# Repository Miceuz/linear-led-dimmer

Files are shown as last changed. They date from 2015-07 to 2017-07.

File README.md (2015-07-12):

# linear-led-dimmer
A linear dimmer for 6W - 12W LED pannels.

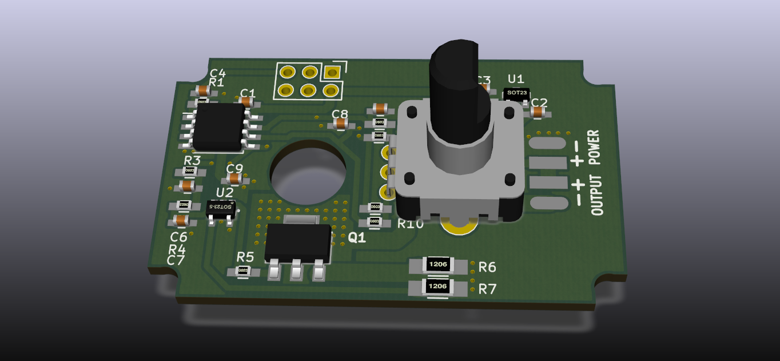
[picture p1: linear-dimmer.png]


This dimmer has to burn some power in order to dimm leds for custom made LED pannel used in cinema settings. We need to resort to crude linear dimming in order to avoid any kind of flicker on camera.



More info and eye candy here:

* Led dimmer on set
* Leds for the light panel
* A cnc cut aluminium case
* 3d printing a grid for led panels
* Led panel for cinema lighting

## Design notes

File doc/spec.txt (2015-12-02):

* Sukurta kino operatoriaus
* Labai aukšta spalvinė kokybė
* Funkcionalus dizainas, 10mm storio, pragalvotas tvirtinimas.
* Su gridu.

 * kur pozicionuoti kitų šviestuvų atžvilgiu?
 * pro pro yra sunkiau nei kitur
 * gasdina LiIon baterija, pirščiukai paprasčiau
 * Kiek laiko
 * Dydis
 * Svoris

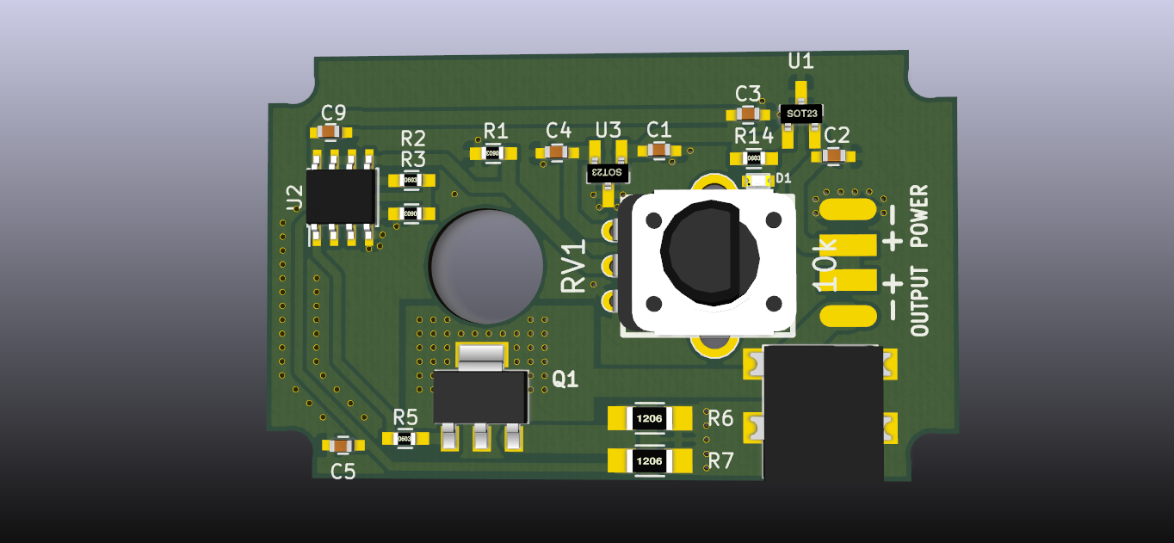
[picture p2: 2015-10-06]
linear-dimmer-v2.0-top.png

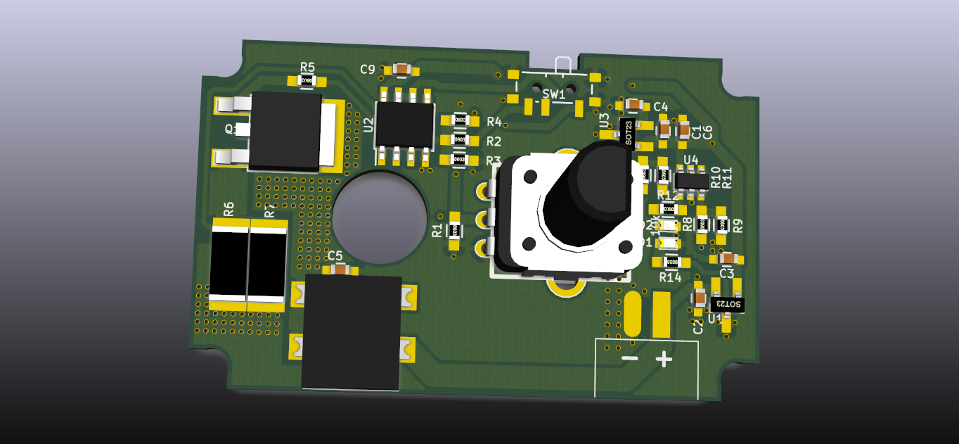
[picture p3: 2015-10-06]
linear-dimmer-v2.0-long-edge-conn.png

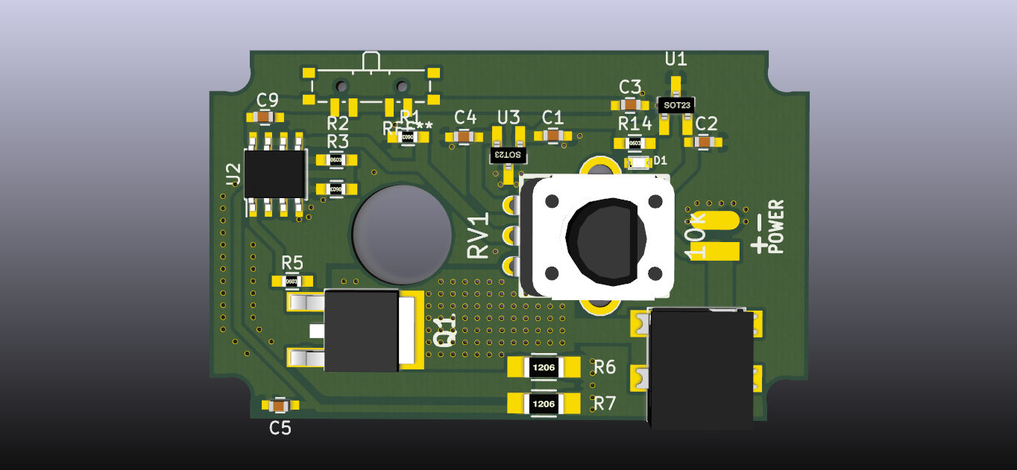
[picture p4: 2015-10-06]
linear-dimmer-v2.0-switch.png

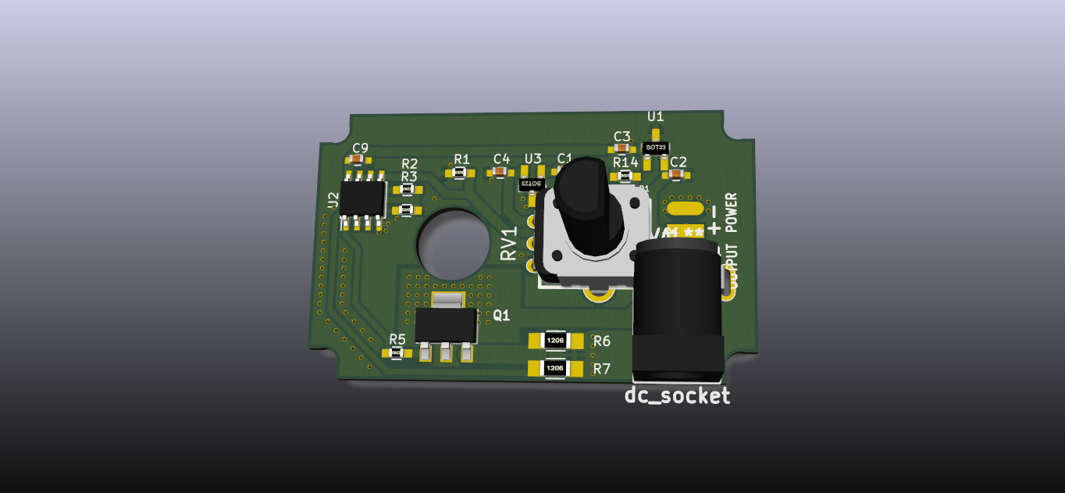
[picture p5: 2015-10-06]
linear-dimmer-v2.0-netelpa.png

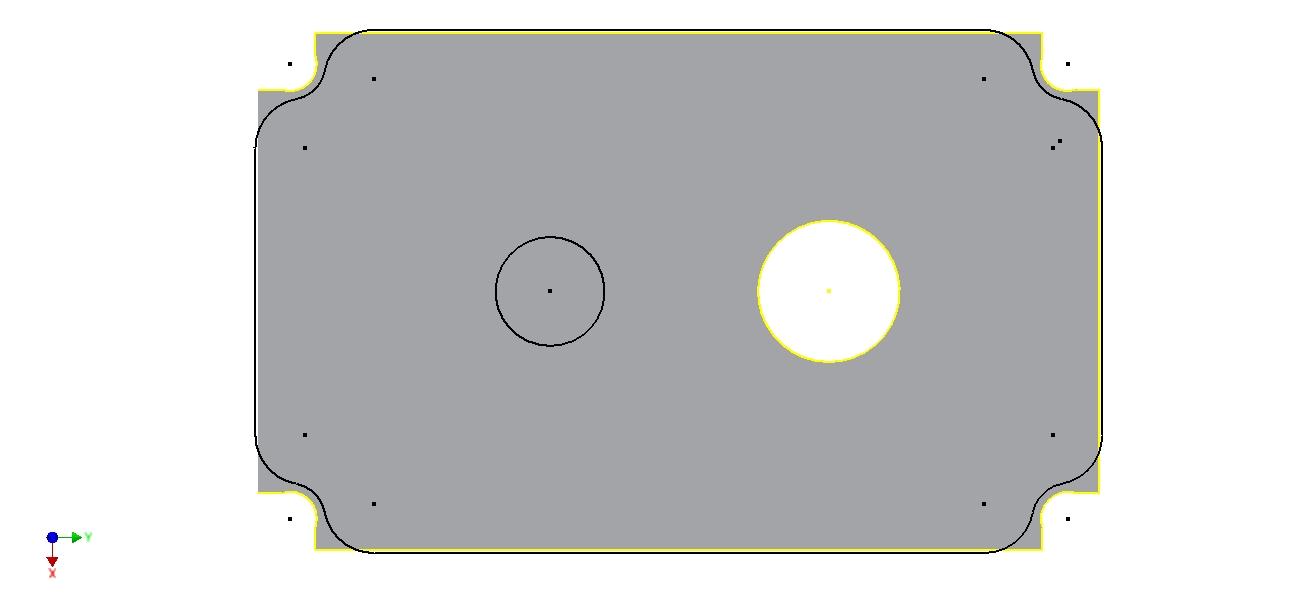
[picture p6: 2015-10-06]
doc/safeline.jpg

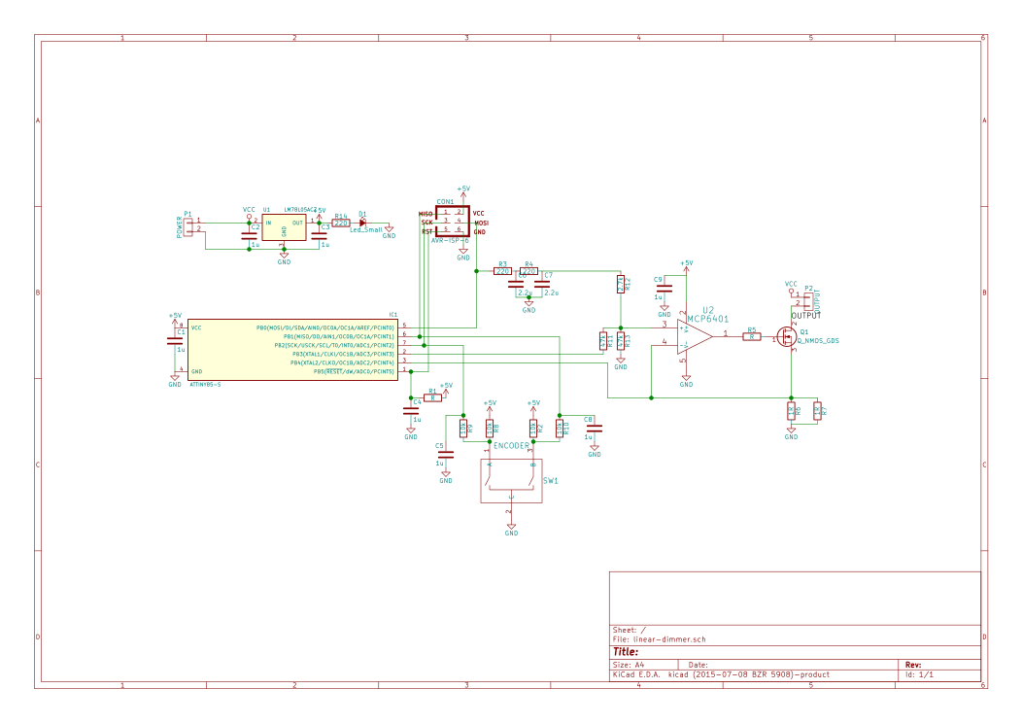
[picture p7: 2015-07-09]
linear-dimmer.sch.png

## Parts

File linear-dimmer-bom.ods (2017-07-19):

Id | Designator | Package | Quantity | Designation | Supplier and ref | Mfg ref | Price @ 10 | # on board
1 | D2 | Led_0603 | 1 | RED |  |  |  | 1 | 0
2 | P1 | pin_socket_2 | 1 | POWER | DNP |  |  | 1 | 0
3 | RV1 | trimmer_alps-rk09k1130ah1 | 1 | 10k | 1191725 (http://lt.farnell.com/alps/rk09k11310kb/pot-rotary-10k-17mm-20/dp/1191725) | RK09K11310KB | 1.35 | 1 | 1.35
4 | C4,C1,C3,C2,C9,C5,C6 | C_0603_HandSoldering | 7 | 1u |  |  | 0.02 | 7 | 0.14
5 | U3 | SOT-23_Handsoldering | 1 | REF3012 | 1470321 (http://lt.farnell.com/texas-instruments/ref3012aidbzt/voltage-ref-series-1-25v-sot-23/dp/1470321) | REF3012AIDBZT | 1.58 | 1 | 1.58
6 | U1 | SOT-23_Handsoldering | 1 | LM78L05ACZ | 1476698 (http://lt.farnell.com/taiwan-semiconductor/ts78l05cx-rf/reg-3-terminal-100ma-smd-sot-23/dp/1476698) | TS78L05CX RF | 0.43 | 1 | 0.43
7 | Q1 | d-pak | 1 | BUK6207-55C | 1863263 (http://lt.farnell.com/nxp/buk6207-55c/mosfet-n-ch-55v-90a-sot428/dp/1863263) | BUK6207-55C | 1.09 | 1 | 1.09
8 | CON1 | WURTH694102107102 | 1 | BARREL_JACK | 2472140 | 694102107102 | 0.78 | 1 | 1.64
9 | D1 | Led_0603 | 1 | BLUE |  |  |  | 1 | 0
10 | R3,R9,R10 | R_0603_HandSoldering | 3 | 10k | 2379939 (http://lt.farnell.com/panasonic-electronic-components/erj3rbd1002v/res-thick-film-10k-0-5-50v-0603/dp/2379939) | ERJ3RBD1002V | 0.044 | 3 | 0.132
11 | R1 | R_0603_HandSoldering | 1 | 2k | 1527506 (http://lt.farnell.com/te-connectivity-neohm/cpf0603f2k0c1/resistor-0603-2k0-1-50ppm/dp/1527506) | CPF0603F2K0C1 | 0.076 | 1 | 0.076
12 | R2 | R_0603_HandSoldering | 1 | 17.4k | 2138436 (http://lt.farnell.com/vishay-draloric/crcw060317k4fkea/resistor-0603-17k4-1/dp/2138436) | CRCW060317K4FKEA | 0.016 | 1 | 0.016
13 | R5,R14,R12 | R_0603_HandSoldering | 3 | 220 |  |  | 0.01 | 3 | 0.03
14 | U2 | SOIC-8_3.9x4.9mm_Pitch1.27mm | 1 | MCP6072 | 1715857 (http://lt.farnell.com/microchip/mcp6072-e-sn/op-amp-dual-1-8v-1-2mhz-8soic/dp/1715857) | MCP6072-E/SN | 0.65 | 1 | 0.65
15 | R7,R6 | r_2512 | 2 | 1R | 1100070 (http://lt.farnell.com/welwyn/lr2512-r50fw/resistor-0-5ohm-2w-2512/dp/1100070) | LR2512-R50FW | 0.86 | 2 | 1.72
16 | R4 | R_0603_HandSoldering | 1 | 3.74k | 1527534 (http://lt.farnell.com/te-connectivity-neohm/cpf0603f3k74c1/resistor-0603-3k74-1-50ppm/dp/1527534) | CPF0603F3K74C1 | 0.0317 | 1 | 0.0317
17 | R8 | R_0603_HandSoldering | 1 | 78.7k | 1527679 (http://lt.farnell.com/te-connectivity-neohm/cpf0603f78k7c1/resistor-0603-78k7-1-50ppm/dp/1527679) | CPF0603F78K7C1 | 0.077 | 1 | 0.077
18 | R11 | R_0603_HandSoldering | 1 | 1M |  |  | 0.01 | 1 | 0.01
19 | SW1 | SW_SPDT_PCM12 | 1 | Switch_SPDT_x2 | 9575146 (http://lt.farnell.com/c-k-components/pcm12smtr/switch-spdt-0-3a-6vdc-smd/dp/9575146) | PCM12SMTR | 0.79 | 1 | 0.79
20 | U4 | sot23-6 | 1 | MCP65R41T | 1863965 (http://lt.farnell.com/microchip/mcp65r41t-2402e-chy/ic-comp-lp-single-6sot23/dp/1863965) | MCP65R41T-2402E/CHY | 0.31 | 1 | 0.31
21 | Output plug |  | 1 |  | 490-PP3-002C | PP3-002C | 0.96 | 1 | 0.96
22 | Lightpipe |  | 1 |  | 2293483 |  | 0.429 | 1 | 0.429
23 | PCB |  | 1 |  |  |  | 1 | 1 | 1
 |  |  |  |  |  |  |  |  | 12.4617

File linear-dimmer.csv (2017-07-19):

Id | Designator | Package | Quantity | Designation | Supplier and ref
1 | D2 | Led_0603 | 1 | RED
2 | P1 | pin_socket_2 | 1 | POWER
3 | RV1 | trimmer_alps-rk09k1130ah1 | 1 | 10k
4 | C4,C1,C3,C2,C9,C5,C6 | C_0603_HandSoldering | 7 | 1u
5 | U3 | SOT-23_Handsoldering | 1 | REF3012
6 | U1 | SOT-23_Handsoldering | 1 | LM78L05ACZ
7 | Q1 | d-pak | 1 | BUK6207-55C
8 | CON1 | WURTH694102107102 | 1 | BARREL_JACK
9 | D1 | Led_0603 | 1 | BLUE
10 | R3,R9,R10 | R_0603_HandSoldering | 3 | 10k
11 | R1 | R_0603_HandSoldering | 1 | 2k
12 | R2 | R_0603_HandSoldering | 1 | 17.4k
13 | R5,R14,R12 | R_0603_HandSoldering | 3 | 220
14 | U2 | SOIC-8_3.9x4.9mm_Pitch1.27mm | 1 | MCP6072
15 | R7,R6 | r_2512 | 2 | 1R
16 | R4 | R_0603_HandSoldering | 1 | 3.74k
17 | R8 | R_0603_HandSoldering | 1 | 78.7k
18 | R11 | R_0603_HandSoldering | 1 | 1M
19 | SW1 | SW_SPDT_PCM12 | 1 | Switch_SPDT_x2
20 | U4 | sot23-6 | 1 | MCP65R41T

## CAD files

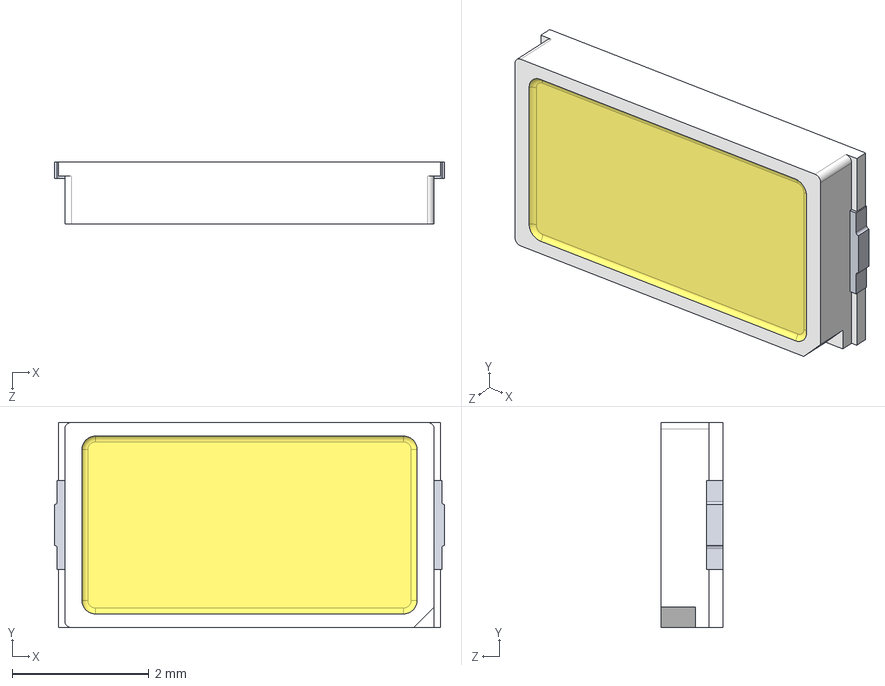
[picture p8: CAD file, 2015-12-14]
3d/User Library-PLCC-2white.step
5.70 x 3.00 x 0.9 mm

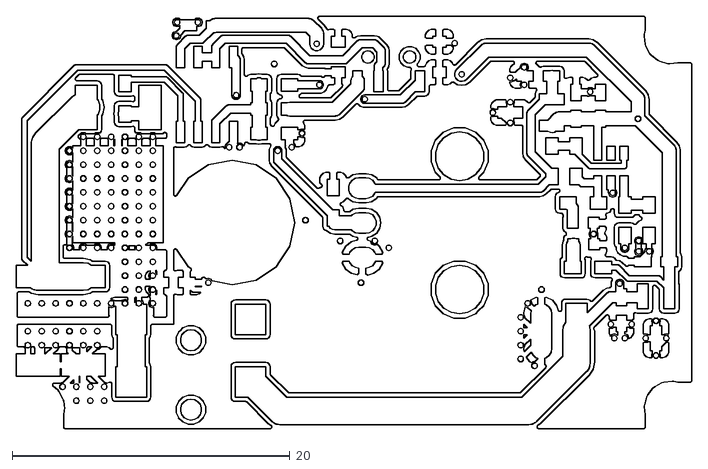
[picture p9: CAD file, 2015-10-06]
dxf/linear-dimmer-F_Cu.dxf
48.7 x 29.7

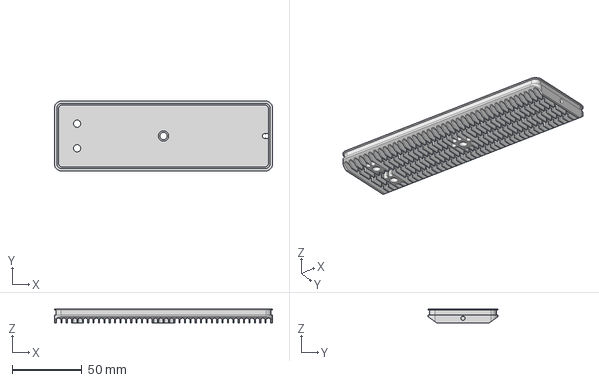
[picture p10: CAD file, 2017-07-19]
pannel/doc/156x50x10 V7 alu pcb V1.stp
156.0 x 50.0 x 10.0 mm

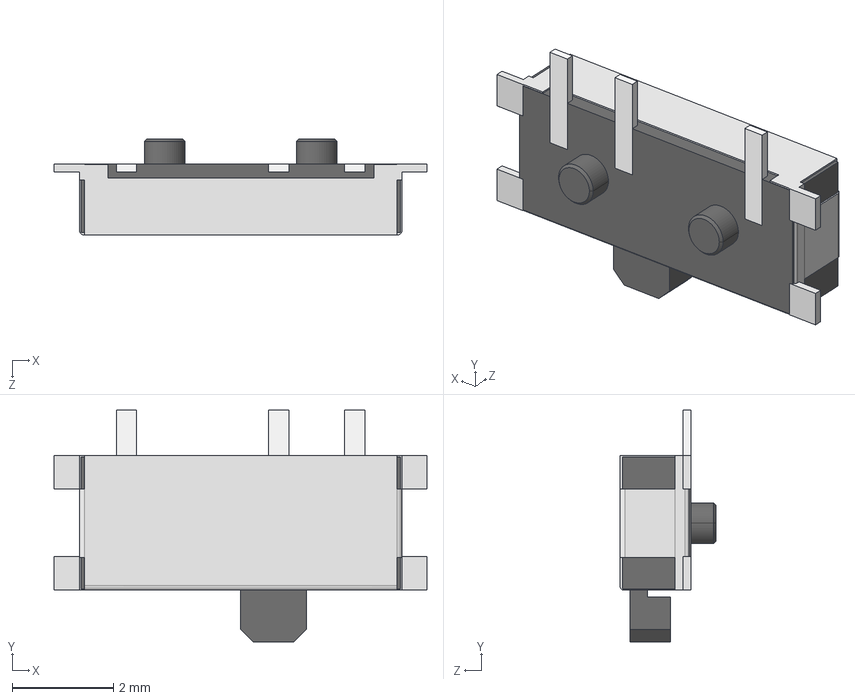
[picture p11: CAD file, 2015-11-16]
3d/User Library-pcm12smtr.STEP
7.35 x 4.57 x 1.90 mm
User Library-pcm12smtr_pcm12smtr_body
User Library-pcm12smtr_pcm12smtr_shield
User Library-pcm12smtr_pcm12smtr_pins
User Library-pcm12smtr_pcm12smtr_slider

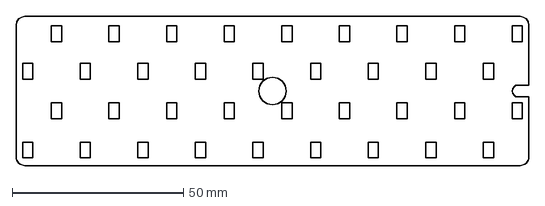
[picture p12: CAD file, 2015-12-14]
doc/Alu-PCB V3.dxf
149.5 x 43.5 mm

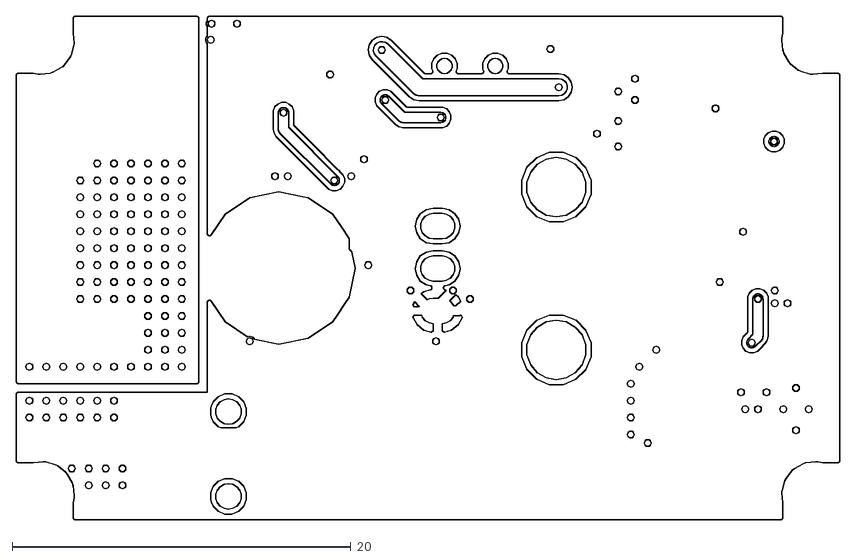
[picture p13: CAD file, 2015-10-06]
dxf/linear-dimmer-B_Cu.dxf
48.6 x 29.7

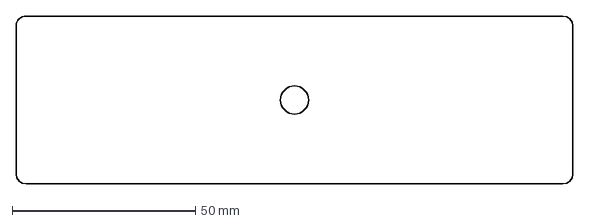
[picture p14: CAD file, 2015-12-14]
doc/Alu-PCB.dxf
151.8 x 45.8 mm

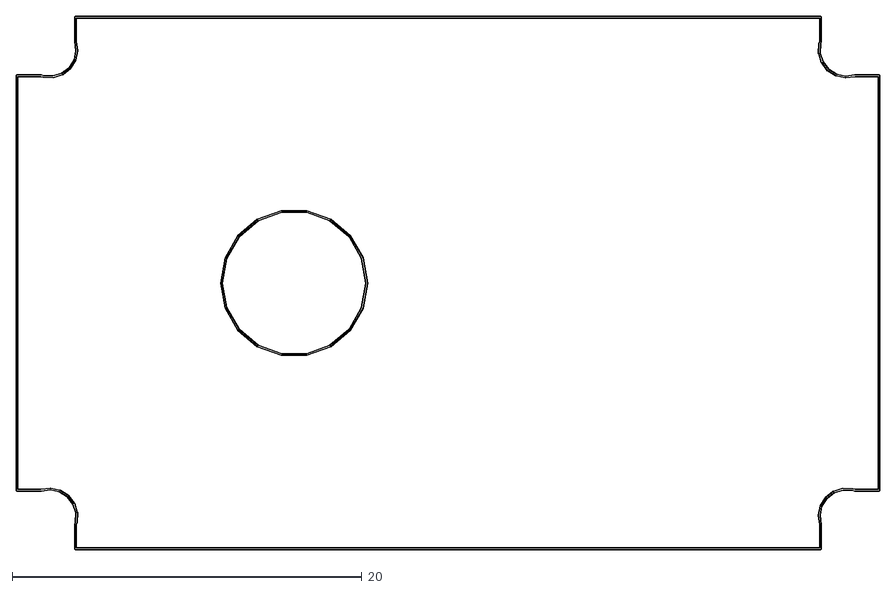
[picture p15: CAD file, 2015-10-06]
dxf/linear-dimmer-Edge_Cuts.dxf
49.4 x 30.5

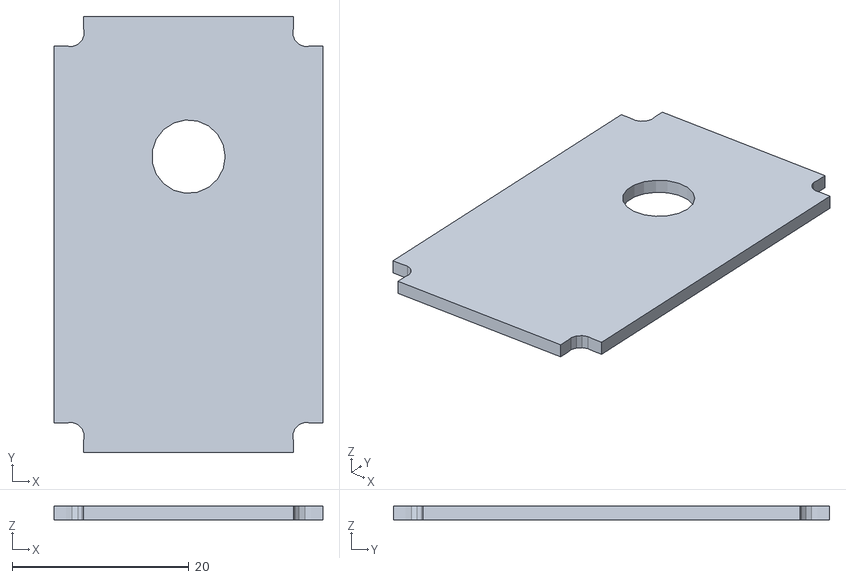
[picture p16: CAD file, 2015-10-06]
doc/safeline.stl
30.4 x 49.3 x 1.60

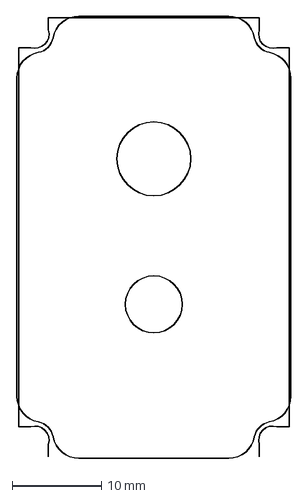
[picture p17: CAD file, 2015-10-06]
doc/safezone.dxf
30.8 x 49.7 mm

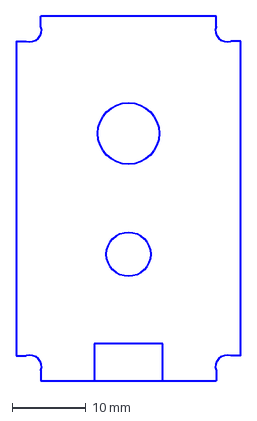
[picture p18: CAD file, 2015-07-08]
doc/PCB V3.dxf
30.4 x 49.3 mm

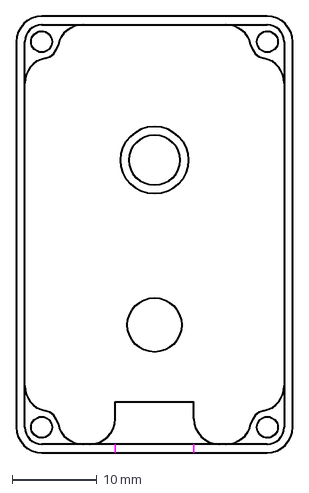
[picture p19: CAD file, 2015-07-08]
doc/dezute korpusas.dxf
32.7 x 51.6 mm

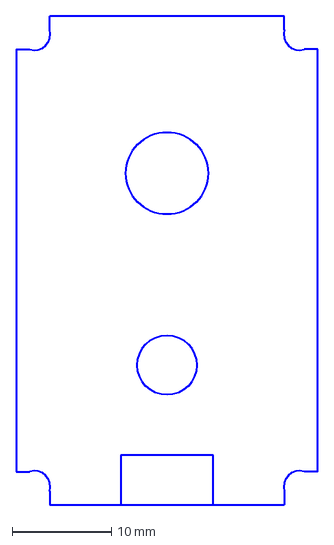
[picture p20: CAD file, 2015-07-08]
doc/PCB.dxf
30.4 x 49.3 mm

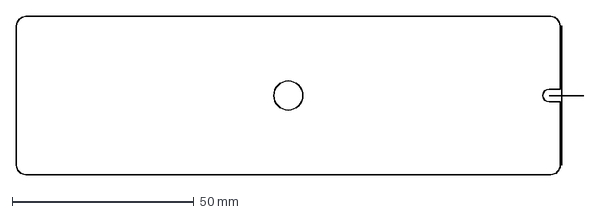
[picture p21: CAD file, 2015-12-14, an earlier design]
doc/Alu-PCB V2.dxf
155.9 x 43.5 mm

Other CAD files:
dxf/linear-dimmer-B_Mask.dxf
dxf/linear-dimmer-B_SilkS.dxf
dxf/linear-dimmer-F_Mask.dxf
dxf/linear-dimmer-F_SilkS.dxf
pannel/doc/156x50x10 V7 alu pcb V1.dwg
pannel/doc/156x50x10 V7 alu pcb V1.stl

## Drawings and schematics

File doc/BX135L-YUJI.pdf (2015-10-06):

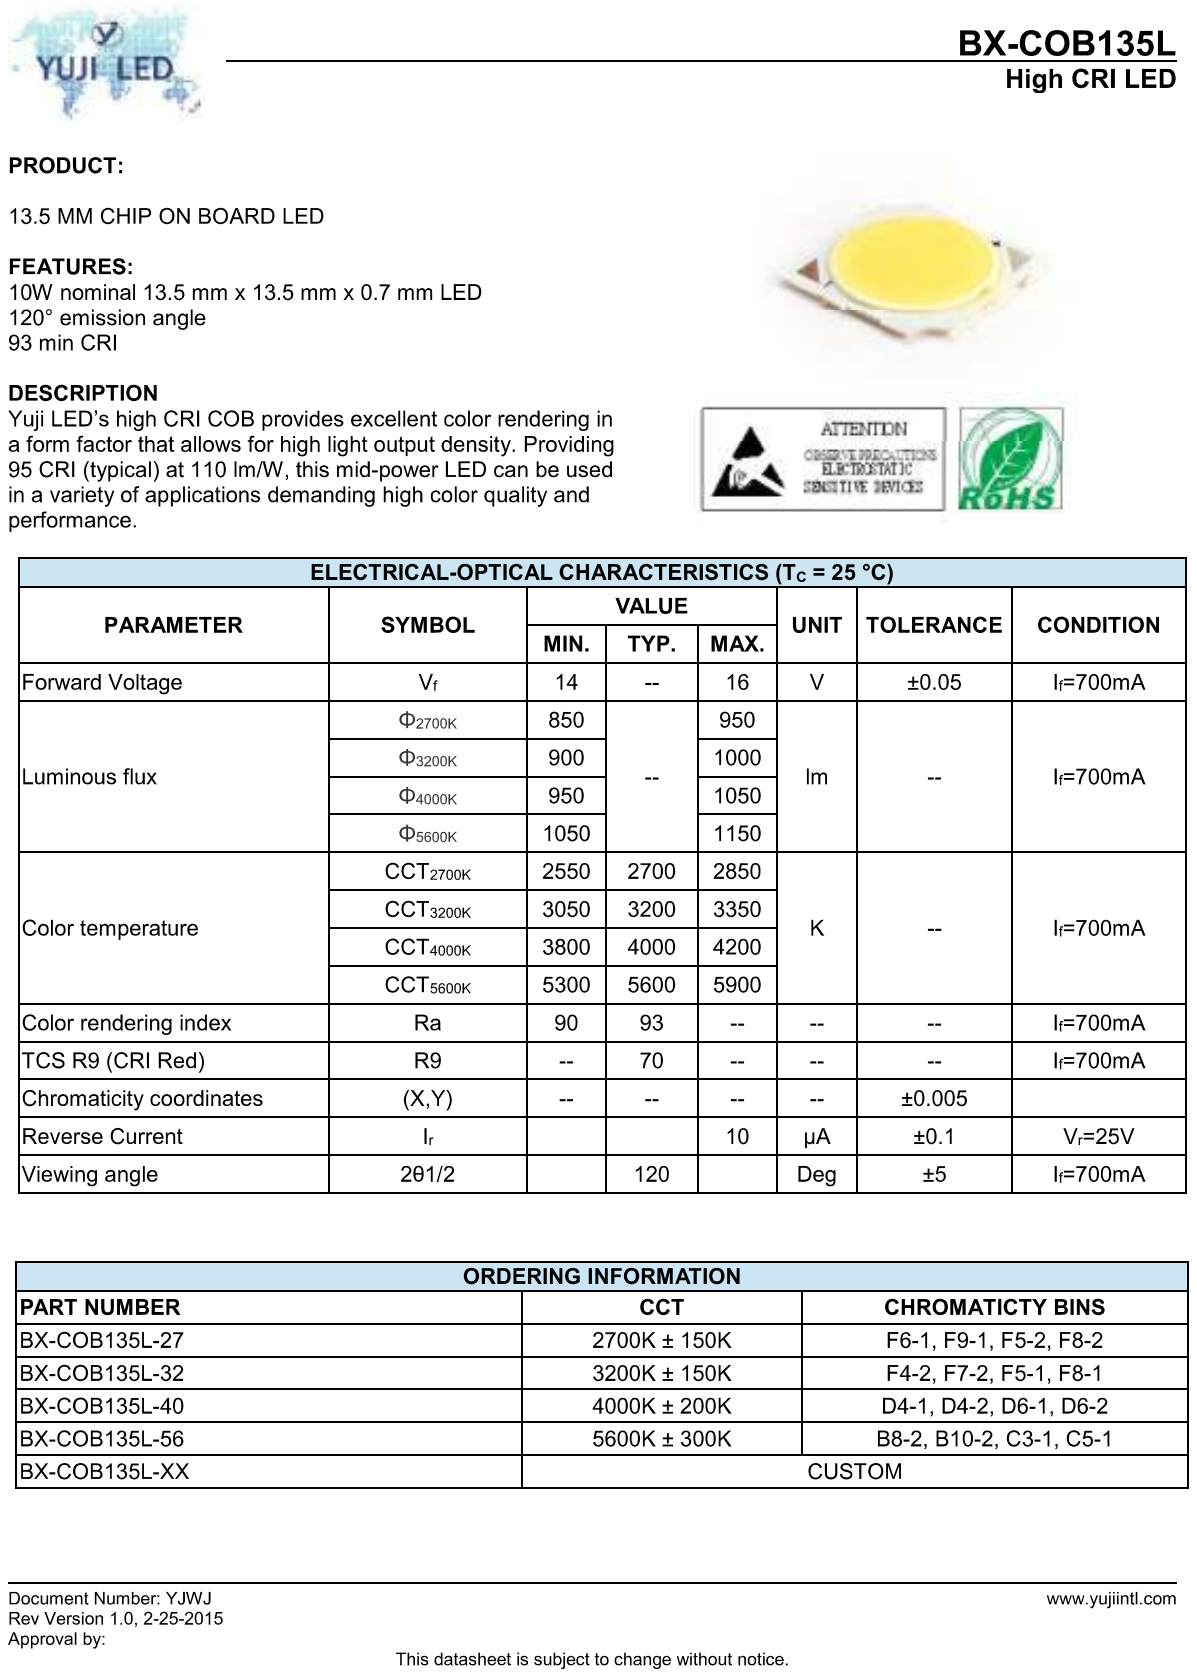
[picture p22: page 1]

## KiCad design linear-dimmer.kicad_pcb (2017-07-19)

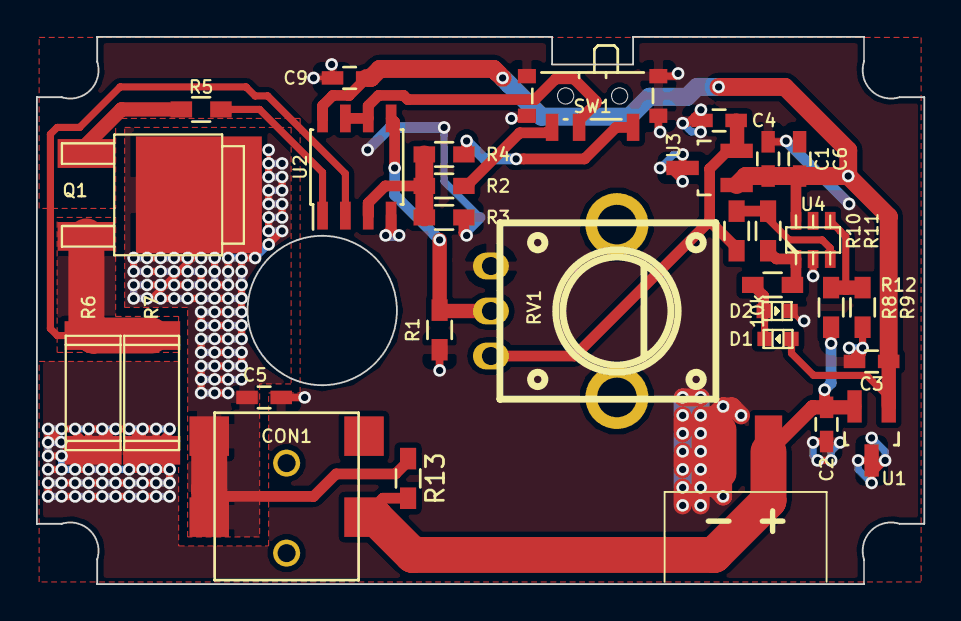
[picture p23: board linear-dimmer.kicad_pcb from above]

Board: 2 copper layers, 49.3 x 30.4 mm, 31 parts (0 on the bottom side), 17 nets.

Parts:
C1, C2, C3, C4, C5, C6, C9: 1u; C_0603_HandSoldering
CON1: BARREL_JACK; WURTH694102107102
D1: BLUE; Led_0603
D2: RED; Led_0603
P1: POWER; pin_socket_2
Q1: BUK6207-55C; d-pak
R1, R13: 2k; R_0603_HandSoldering
R2: 17.4k; R_0603_HandSoldering
R3, R9, R10: 10k; R_0603_HandSoldering
R4: 45.3k; R_0603_HandSoldering
R5, R12: 220; R_0603_HandSoldering
R6, R7: 0R5; r_2512
R8: 78.7k; R_0603_HandSoldering
R11: 1M; R_0603_HandSoldering
RV1: 10k; trimmer_alps-rk09k1130ah1
SW1: Switch_SPDT_x2; SW_SPDT_PCM12
U1: LM78L05ACZ; SOT-23_Handsoldering
U2: MCP6072; SOIC-8_3.9x4.9mm_Pitch1.27mm
U3: REF3012; SOT-23_Handsoldering
U4: MCP65R41T; sot23-6

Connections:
+1.2V: C4.1, R10.1, RV1.3, U3.2
+5V: C1.1, C3.1, C6.1, C9.1, D1.1, U1.1, U2.8, U3.1, U4.6
/OUTPUT: C5.1, CON1.1, Q1.2, R13.2
GND: C1.2, C2.2, C3.2, C4.2, C5.2, C6.2, C9.2, D2.2, P1.2, R1.2, R3.2, R6.2, R7.2, R9.2, RV1.1, U1.3, U2.4, U3.3, U4.2
unnamed: D1.2, D2.1, R12.2
unnamed: Q1.1, R5.2
unnamed: Q1.3, R6.1, R7.1, U2.2
unnamed: R1.1, RV1.2, U2.5
unnamed: R2.1, R3.1, R4.1, U2.3
unnamed: R2.2, SW1.3
unnamed: R4.2, SW1.1
unnamed: R5.1, U2.1
unnamed: R8.2, R9.1, U4.4
unnamed: R10.2, R11.1, U4.3
unnamed: R11.2, R12.1, U4.1
unnamed: SW1.2, U2.6, U2.7
VCC: C2.1, CON1.2, P1.1, R8.1, R13.1, U1.2

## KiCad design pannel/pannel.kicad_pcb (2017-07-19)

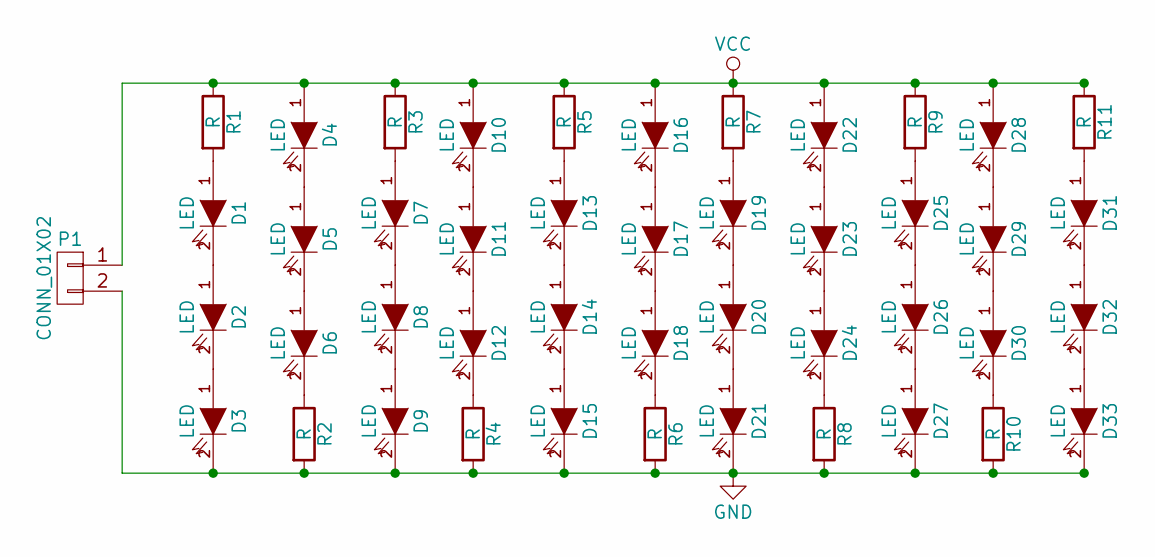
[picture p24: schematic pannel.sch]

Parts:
D1, D2, D3, D4, D5, D6, D7, D8, D9, D10, D11, D12, D13, D14, D15, D16, D17, D18, D19, D20, D21, D22, D23, D24, D25, D26, D27, D28, D29, D30, D31, D32, D33: LED; LED5730; PartNo ?
P1: CONN_01X02; Pin_Header_Angled_1x02; PartNo ?
R1, R2, R3, R4, R5, R6, R7, R8, R9, R10, R11: R; R_2010; PartNo MC2010W2F330LT4E

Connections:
GND: D3.2 (K), D9.2 (K), D15.2 (K), D21.2 (K), D27.2 (K), D33.2 (K), P1.2, R2.2, R4.2, R6.2, R8.2, R10.2
unnamed: D1.1 (A), R1.2
unnamed: D1.2 (K), D2.1 (A)
unnamed: D2.2 (K), D3.1 (A)
unnamed: D4.2 (K), D5.1 (A)
unnamed: D5.2 (K), D6.1 (A)
unnamed: D6.2 (K), R2.1
unnamed: D7.1 (A), R3.2
unnamed: D7.2 (K), D8.1 (A)
unnamed: D8.2 (K), D9.1 (A)
unnamed: D10.2 (K), D11.1 (A)
unnamed: D11.2 (K), D12.1 (A)
unnamed: D12.2 (K), R4.1
unnamed: D13.1 (A), R5.2
unnamed: D13.2 (K), D14.1 (A)
unnamed: D14.2 (K), D15.1 (A)
unnamed: D16.2 (K), D17.1 (A)
unnamed: D17.2 (K), D18.1 (A)
unnamed: D18.2 (K), R6.1
unnamed: D19.1 (A), R7.2
unnamed: D19.2 (K), D20.1 (A)
unnamed: D20.2 (K), D21.1 (A)
unnamed: D22.2 (K), D23.1 (A)
unnamed: D23.2 (K), D24.1 (A)
unnamed: D24.2 (K), R8.1
unnamed: D25.1 (A), R9.2
unnamed: D25.2 (K), D26.1 (A)
unnamed: D26.2 (K), D27.1 (A)
unnamed: D28.2 (K), D29.1 (A)
unnamed: D29.2 (K), D30.1 (A)
unnamed: D30.2 (K), R10.1
unnamed: D31.1 (A), R11.2
unnamed: D31.2 (K), D32.1 (A)
unnamed: D32.2 (K), D33.1 (A)
VCC: D4.1 (A), D10.1 (A), D16.1 (A), D22.1 (A), D28.1 (A), P1.1, R1.1, R3.1, R5.1, R7.1, R9.1, R11.1

Board: 2 copper layers, 45 parts (0 on the bottom side), 35 nets, no tracks yet.

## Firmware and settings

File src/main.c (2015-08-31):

#include <avr/io.h>
#include <inttypes.h>
#include <util/delay.h>
#include <avr/pgmspace.h>
#include <avr/interrupt.h>



const uint8_t pwm[] PROGMEM ={
0,
1,
2,
3,
3,
4,
5,
6,
7,
8,
9,
10,
11,
12,
13,
14,
15,
16,
17,
18,
19,
20,
21,
22,
23,
24,
25,
25,
26,
27,
28,
29,
30,
31,
32,
33,
34,
35,
36,
36,
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

inline static void pwmInit() {
	OCR0A = 0;
	DDRB |= _BV(PB0);
	TCCR0A |= _BV(WGM00) | _BV(WGM01) | _BV(COM0A1);
	TCCR0B |= _BV(CS00);
}

inline static void pwmSet(uint8_t level) {
	OCR0A = level;
	if(0 != level) {
		TCCR0B |= _BV(CS00);
	} else {
		TCCR0B = 0;
	}
}

inline static void encoderInit() {
	DDRB &= ~_BV(PB1);
	DDRB &= ~_BV(PB2);

}

#define ENC_A PB2
#define ENC_B PB1
#define ENC_PORT PINB

int8_t encoderRead() {
	static int8_t enc_states[] = {0,-1,1,0,1,0,0,-1,-1,0,0,1,0,1,-1,0};
//	static int8_t enc_states[] = {0,0,0,0,1,0,0,-1,0,0,0,0,0,0,0,0};
	static uint8_t old_AB = 0;
	old_AB <<= 2;                   //remember previous state
	uint8_t t = ((( 0 == (ENC_PORT & _BV(ENC_A))) << 1) | (0 == (ENC_PORT & _BV(ENC_B))));

	old_AB |= t;  //add current state
	return ( enc_states[( old_AB & 0x0f )]);
}

volatile uint32_t millis = 0;

uint8_t targetPwm = 0;
uint8_t currentPwm = 0;

ISR(TIMER1_OVF_vect) {
	if(0 == (millis % 5)) {
		if(targetPwm > currentPwm && currentPwm < 254) {
			currentPwm++;
		} else if(targetPwm < currentPwm && currentPwm > 0) {
			currentPwm--;
		}
		pwmSet(currentPwm);
	}
	millis++;
}

void timerInit() {
	TIMSK |= _BV(TOIE1);
	TCCR1 |= _BV(CS12) | _BV(CS11);

}

void main() {
	timerInit();
	sei();
	pwmInit();
	int16_t i = 0;
	uint32_t lastDetentTimestamp;
	pwmSet(0);
	int8_t encoderPulses = 0;
	while(1) {
		encoderPulses += encoderRead();

		if( encoderPulses > 3 || encoderPulses < -3 ) {
			int8_t encoderStep = encoderPulses / 4;

			if(millis - lastDetentTimestamp < 20) {
				i+= encoderStep*10;
			} else if(millis - lastDetentTimestamp < 30) {
				i+= encoderStep*5;
			} else if(millis - lastDetentTimestamp < 40) {
				i+= encoderStep*2;
			} else {
				i+= encoderStep;
			}
			if(i > 187) {
				i = 187;
			} 
			if(i < 0) {
				i = 0;
			}
			targetPwm = (uint8_t) pgm_read_byte(&(pwm[i]));
			lastDetentTimestamp = millis;
			//_delay_ms(1);
			encoderPulses = 0;
		}
//		_delay_ms(5);
	}
}

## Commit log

2015-07-08 Add LED, shuffle stuff around
    [linear-dimmer.kicad_pcb, linear-dimmer.sch]
2015-07-08 Shuffle stuff around, hide footprints in schematics
    [linear-dimmer.kicad_pcb, linear-dimmer.sch]
2015-07-09 Shuffle stuff around, generate gerbers
    [linear-dimmer-B_Cu.gbr, linear-dimmer-B_Mask.gbr, linear-dimmer-B_SilkS.gbr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]
2015-07-12 Add bom
    [linear-dimmer-bom.ods]
2015-07-12 Set some resistor values and FarnellIDs
    [linear-dimmer.sch]
2015-07-12 Some trivial changes
    [linear-dimmer.kicad_pcb]
2015-08-31 Add datasheet for the best diodes
2015-08-31 Add a switcher simulation - this one does not work good, but anyway, have it here
2015-08-31 Redraw schematics with just a pot and an opamp current source
    [linear-dimmer.sch]
2015-09-20 Add buffer opamp, choose a different opamp, redraw the PCB with dumb linead current source
    [linear-dimmer.kicad_pcb, linear-dimmer.sch]
2015-10-06 Ready to send to PCB house
    [linear-dimmer-B_Cu.dxf, linear-dimmer-B_Mask.dxf, linear-dimmer-B_SilkS.dxf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]
2015-10-06 Last stray save
    [linear-dimmer.kicad_pcb]
2015-10-22 Update the value for shunt resistors, recalculate divider values accordingly
    [linear-dimmer.sch]
2015-10-22 Put the power on led to comparator so that blue changes to red on battery low
    [linear-dimmer.kicad_pcb, linear-dimmer.sch]
2015-10-22 Schematic changes after new kicad version
    [linear-dimmer.sch]
2015-10-22 Stray fogotten edit to bom
    [linear-dimmer-bom.ods]
2015-10-24 Flip comparator inputs, flip potentiometer
    [linear-dimmer.sch]
2015-10-24 Add a dummy load resistor so that opamp will be forced to swing the output down at the lowest current setting turning the LEDs off
    [linear-dimmer.sch]
2015-10-24 Put load to the proper place in schematics
    [linear-dimmer.sch]
2015-10-24 Implement changes in PCB
    [linear-dimmer.kicad_pcb]
2015-11-16 Add 3d model for the switch
    [User Library-pcm12smtr.STEP, linear-dimmer.kicad_pcb]
2015-11-16 Add amperage markings
    [linear-dimmer.kicad_pcb]
2015-12-02 Generate gerbers for the fixed version of linear dimmer
    [linear-dimmer-B.Cu.gbr, linear-dimmer-B.Mask.gbr, linear-dimmer-B.SilkS.gbr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]
2015-12-02 Fix version number on silkscreen
    [linear-dimmer.kicad_pcb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]
2015-12-02 Add LED pannel for aluminium PCB
    [Alu-PCB V2.dxf, Alu-PCB V3.dxf, Alu-PCB.dxf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]
2015-12-02 Add the beginning of spec/marketing material
2015-12-14 Swap silkscreen markings of the output current switch
    [linear-dimmer.kicad_pcb]
2015-12-14 Add a resistor for the blue led to embarass less
    [linear-dimmer-bom.ods, linear-dimmer.sch]
2017-07-19 all the rest
    [156x50x10 V7 alu pcb V1.dwg, 156x50x10 V7 alu pcb V1.stl, 156x50x10 V7 alu pcb V1.stp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]
